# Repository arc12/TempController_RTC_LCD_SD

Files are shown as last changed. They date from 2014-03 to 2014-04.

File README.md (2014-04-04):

Multiple DS18B20 temperature sensors with LCD display, SD card logging, remote control via Serial/USB, real time clock, and up to control an output.

Intended for compilation in Atmel Studio and deployment on a custom ATMega328 based circuit. See source code for notes on use with Arduino IDE.

Various library dependencies not in github yet (will be separate repos). See *.atsln

The idea of this is to have 3 temp sensors: one in a well inside the beer (5 gallon bucket), one inside a ply-wood box (contains a heater pad and the bucket), and one in the outside room. Logging temperature for all three will give an idea of the thermal properties of the assembly and of the heat produced by fermentation. In the first instance, a very simple control rule will be used, taking only the temperature from in the wort and testing for a min temperature with fixed hysteresis. See the MS Word Doc.

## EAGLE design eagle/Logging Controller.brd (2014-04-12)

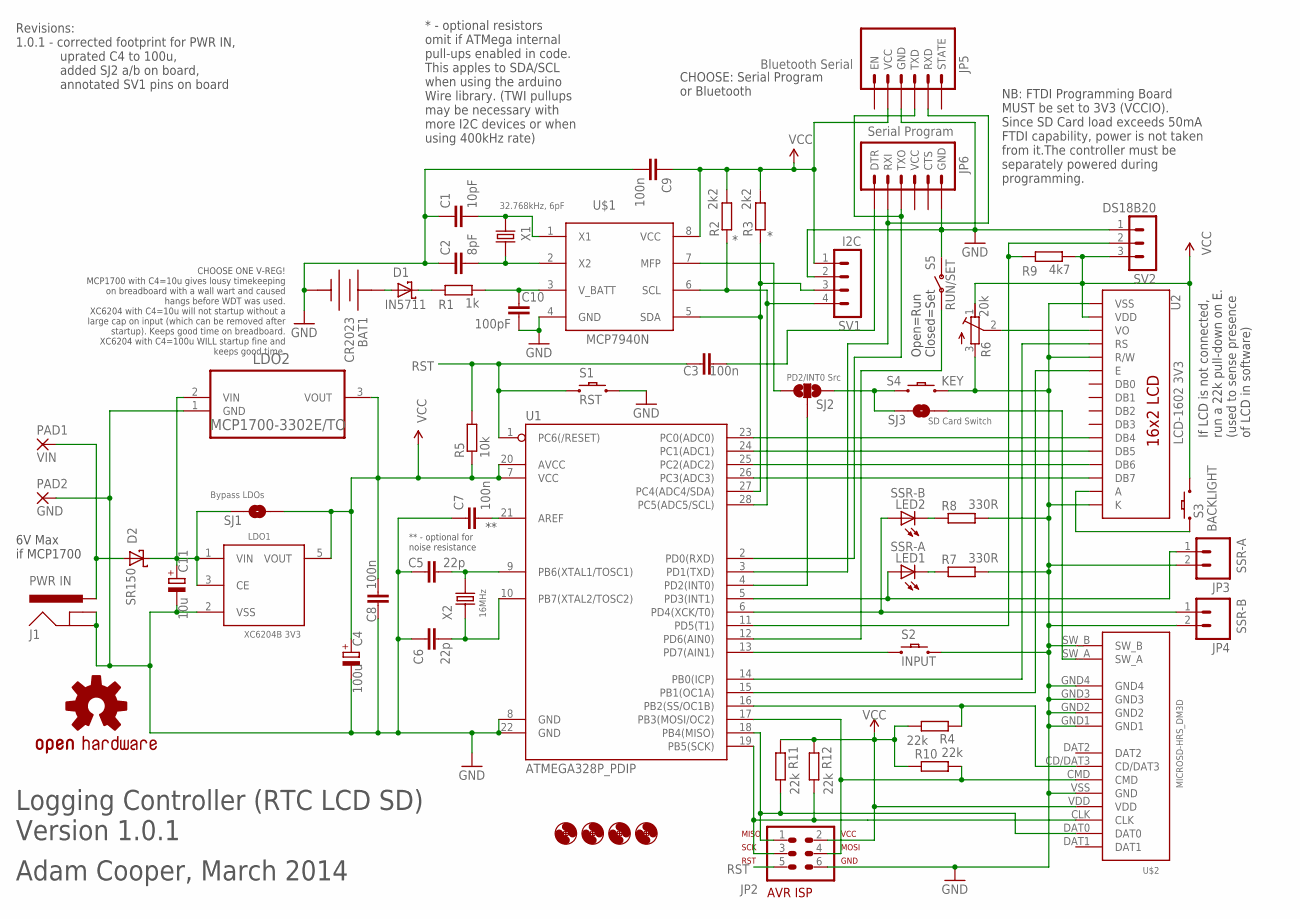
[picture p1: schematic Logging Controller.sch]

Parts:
BAT1: CR2023; KEYSTONE3003
C1: 10pF; C025-024X044
C2: 8pF; C025-024X044
C3, C7, C8, C9: 100n; C025-024X044
C4: 100u; E2,5-5
C5, C6: 22p; C025-024X044
C10: 100pF; C025-024X044
C11: 10u; E2,5-5
D1: IN5711; DO35-7
D2: SR150; DO-41
H1, H2, H3, H4: MOUNT-HOLE3.0_REDUCED; 3,0
J1: PWR IN; POWER_JACK_SLOT2
JP2: AVR-ISP; AVR-ISP-6
JP3: SSR-A; 1X02
JP4: SSR-B; 1X02
JP5: Bluetooth Serial; BT_MOD_ROUND
JP6: Serial Program; 1X06
LDO1: XC6204B 3V3; SOT23-5
LDO2: MCP1700-3302E/TO; TO127P254X495-3
LED1: SSR-A; LED5MM
LED2: SSR-B; LED5MM
LOGO1: OSHW-LOGOS; OSHW-LOGO-S
PAD1: VIN; 2,54/1,1
PAD2: GND; 2,54/1,1
R1: 1k; 0204/7
R2, R3: 2k2; 0204/7
R4, R10, R11, R12: 22k; 0204/7
R5: 10k; 0204/7
R6: 20k; RTRIMT93YB
R7, R8: 330R; 0204/7
R9: 4k7; 0204/7
S1: RST; TACTILE-PTH
S2: INPUT; OFF_BOARD_SPST
S3: BACKLIGHT; OFF_BOARD_SPST
S4: KEY; OFF_BOARD_SPST
S5: RUN/SET; SWITCH-SPST-OFFBOARD
SJ1: Bypass LDOs; SJ_2S-NO
SJ2: PD2/INT0 Src; SJ_3
SJ3: SD Card Switch; SJ_2S-NO
SV1: I2C; MA04-1
SV2: DS18B20; MA03-1
U1: ATMEGA328P_PDIP; DIL28-3@1
U2: LCD-1602 3V3; LCD-16X2_NOSILK
U$1: MCP7940N; DIL08
U$2: MICROSD-HRS_DM3D; DM3D
X1: 32.768kHz, 6pF; TC26H
X2: 16MHz; HC49U-V

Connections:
GND: BAT1.NEG, C1.1, C2.1, C4.-, C5.1, C6.1, C7.1, C8.1, C9.2, C10.1, C11.-, J1.GND, J1.GND2 (GNDBREAK), JP2.6, JP3.2, JP4.2, JP5.4 (GND), JP6.6 (GND), LDO1.2 (VSS), LDO2.1 (GND), PAD2.1, R6.3 (E), R7.2, R8.2, S1.3 (2), S2.P$2 (2), S4.P$2 (2), S5.1 (O), SV1.2, SV2.1, U1.8 (GND), U1.22 (GND), U2.1 (VSS), U2.5 (R/W), U2.16 (K), U$1.4 (GND), U$2.GND1, U$2.GND2, U$2.GND3, U$2.GND4, U$2.SW_B, U$2.VSS (GND)
unnamed: R9.1, SV2.2, U1.11 (PD5(T1))
unnamed: R4.1, U1.16 (PB2(SS/OC1B)), U$2.CD/DAT3
unnamed: U1.14 (PB0(ICP)), U2.4 (RS)
unnamed: U1.15 (PB1(OC1A)), U2.6 (E)
unnamed: U1.23 (PC0(ADC0)), U2.11 (DB4)
unnamed: U1.24 (PC1(ADC1)), U2.12 (DB5)
unnamed: U1.25 (PC2(ADC2)), U2.13 (DB6)
unnamed: U1.26 (PC3(ADC3)), U2.14 (DB7)
unnamed: S3.P$1 (1), U2.15 (A)
unnamed: S2.P$1 (1), U1.13 (PD7(AIN1))
unnamed: S5.2, U1.12 (PD6(AIN0))
unnamed: JP4.1, LED2.A, U1.6 (PD4(XCK/T0))
unnamed: JP3.1, LED1.A, U1.5 (PD3(INT1))
unnamed: LED2.K (C), R8.1
unnamed: LED1.K (C), R7.1
unnamed: S4.P$1 (1), SJ2.3, SJ3.1
unnamed: SJ2.2, U1.4 (PD2(INT0))
unnamed: R6.2 (S), U2.3 (VO)
unnamed: SJ3.2, U$2.SW_A
unnamed: SJ2.1, U$1.7 (MFP)
unnamed: JP5.3 (TXD), JP6.3 (TXO), U1.2 (PD0(RXD))
unnamed: JP2.4, R10.2, U1.17 (PB3(MOSI/OC2)), U$2.CMD
unnamed: JP2.1, R11.2, U1.18 (PB4(MISO)), U$2.DAT0
unnamed: JP5.2 (RXD), JP6.2 (RXI), U1.3 (PD1(TXD))
unnamed: R3.1, SV1.3, U1.27 (PC4(ADC4/SDA)), U$1.5 (SDA)
unnamed: R2.1, SV1.4, U1.28 (PC5(ADC5/SCL)), U$1.6 (SCL)
unnamed: C1.2, U$1.1 (X1), X1.2
unnamed: C2.2, U$1.2 (X2), X1.1
unnamed: BAT1.POS, BAT1.POS1 (POS), D1.A
unnamed: D1.C, R1.1
unnamed: C10.2, R1.2, U$1.3 (V_BATT)
unnamed: C11.+, D2.C, LDO1.1 (VIN), LDO1.3 (CE), LDO2.2 (VIN), SJ1.1
unnamed: D2.A, J1.POS (PWR), PAD1.1
unnamed: C5.2, U1.9 (PB6(XTAL1/TOSC1)), X2.2
unnamed: C3.2, JP6.1 (DTR)
unnamed: C6.2, U1.10 (PB7(XTAL2/TOSC2)), X2.1
unnamed: JP2.3, R12.2, U1.19 (PB5(SCK)), U$2.CLK
unnamed: C7.2, U1.21 (AREF)
RST: C3.1, JP2.5, R5.2, S1.1, U1.1 (PC6(/RESET))
VCC: C4.+, C8.2, C9.1, JP2.2, JP5.5 (VCC), LDO1.5 (VOUT), LDO2.3 (VOUT), R2.2, R3.2, R4.2, R5.1, R6.1 (A), R9.2, R10.1, R11.1, R12.1, S3.P$2 (2), SJ1.2, SV1.1, SV2.3, U1.7 (VCC), U1.20 (AVCC), U2.2 (VDD), U$1.8 (VCC), U$2.VDD

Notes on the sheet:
Adam Cooper, March 2014
Logging Controller (RTC LCD SD) Version 1.0.1
Open=Run Closed=Set
* - optional resistors omit if ATMega internal pull-ups enabled in code. This apples to SDA/SCL when using the arduino Wire library. (TWI pullups may be necessary with more I2C devices or when using 400kHz rate)
6V Max if MCP1700
** - optional for noise resistance
NB: FTDI Programming Board MUST be set to 3V3 (VCCIO). Since SD Card load exceeds 50mA FTDI capability, power is not taken from it.The controller must be separately powered during programming.
CHOOSE ONE V-REG! MCP1700 with C4=10u gives lousy timekeeping on breadboard with a wall wart and caused hangs before WDT was used. XC6204 with C4=10u will not startup without a large cap on input (which can be removed after startup). Keeps good time on breadboard. XC6204 with C4=100u WILL startup f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
If LCD is not connected, run a 22k pull-down on E. (used to sense presence of LCD in software)
CHOOSE: Serial Program or Bluetooth
Revisions: 1.0.1 - corrected footprint for PWR IN, uprated C4 to 100u, added SJ2 a/b on board, annotated SV1 pins on board

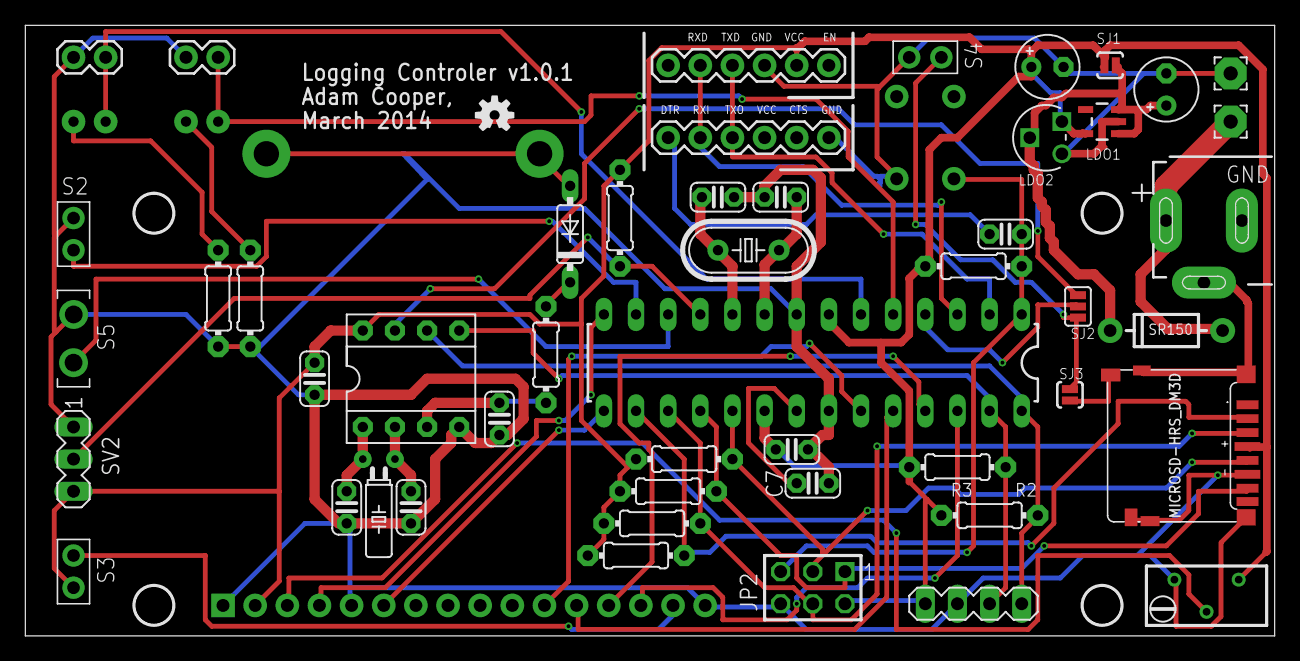
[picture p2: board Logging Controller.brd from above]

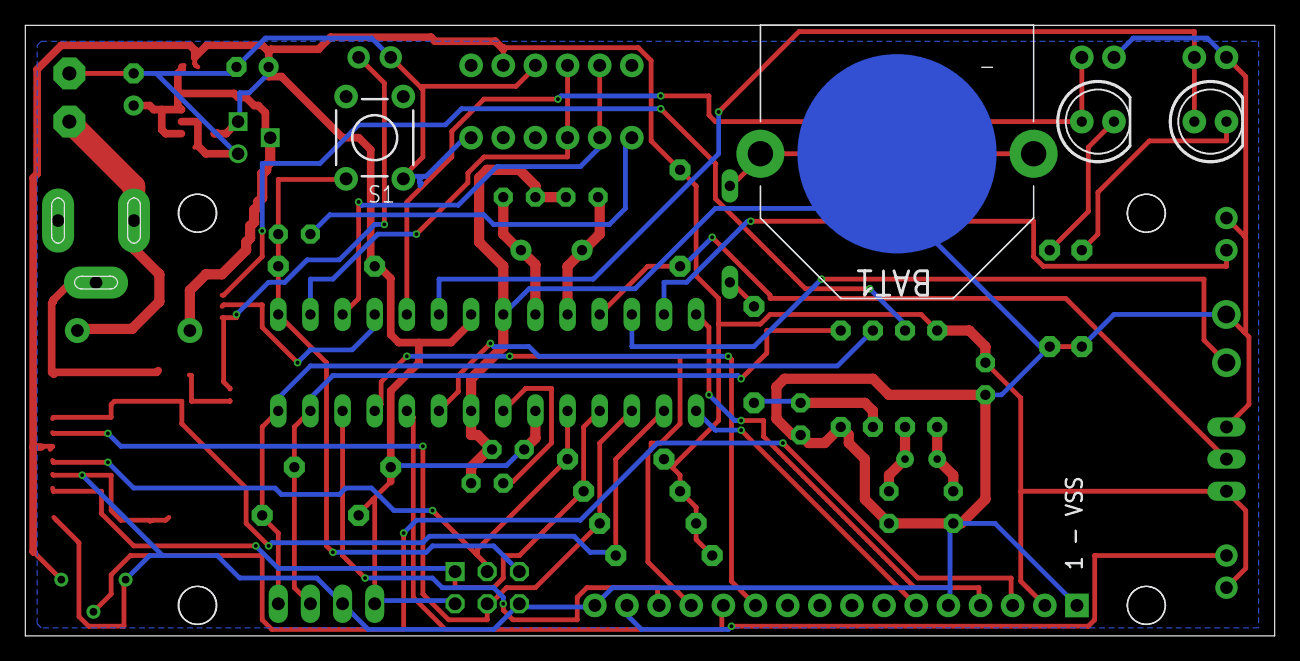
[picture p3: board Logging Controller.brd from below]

Board: 2 copper layers, 98.7 x 48.2 mm, 59 parts (5 on the bottom side), 41 nets.

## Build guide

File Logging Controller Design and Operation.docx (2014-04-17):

# Logging Temp Controller v1

If hardware (schematic and layout) and software have mutually dependent changes, use a new full version number. Use “dot” minor versions for functional changes without HW/SW interdependency. Use “double-dot” sub-minor for bug fix changes. E.g. a PCB layout bug fix to a v1 would number the PCB only as v1.0.1

# Technical Issues

## Power

Assumed to be a 5V wall-wart regulated down to 3V3 because of SD card requirements. Power is NOT taken from USB, even when connected (the internal 3V3 regulator in a FT232R is not rated to deliver sufficient current for SD Card).

Two options for LDOs are accommodated. Only use one!

NB if programming with a FT232RL board, it MUST be set to 3V3 I/O.

## Solder Jumpers

SJ1: bypass LDO if 3V3 supply is used.

SJ2: select input to PD2, either a) use to get a square wave or alarm interrupt from the MCP7940, or b) use to sense a keypress on S4 or SD card insertion

SJ3: connect SD card insertion switch. S4 should be omitted in this case

Normal use expected to have SJ1 open, SJ2 to option (b) and SJ3 closed.

## Omitted Components

S4 – because of SD card switch

R2, R3 - when using the Arduino Wire library, ATMega internal pull-ups enabled in code. TWI pullups may be necessary with more I2C devices or when using 400kHz rate)

JP4 – not expecting to control 2 outputs, “for future use” (LED2 used as over-range signal)

SV1 – for possible extra I2C components “future use”

JP2 – don’t expect to use ISP

C7 – there is no ADC use. This is present “for future use”.

** it may be possible to omit some/all of the 22k pull-ups on the SD Card lines but these seem to be generally recommended.

## LCD Notes

This is a 3V3 device. Some 3V3 versions have peculiar requirements for V0.

The LCD may be omitted. Place a 22k resistor from E to ground; the software will sense this and skip LCD output code.

## Watchdog

Unless #define WATCHDOG has been commented out, the watchdog timer is set to 8s and a delay of >8s between calling loop() will cause a reset. This is useful because if there is a crash while outA is switched on, the brew will overheat (or if off, over-cool!).

# User Notes

## Logging to SD Card and to Serial

SD card presence is detected on startup. Logging to the card will be skipped if no card is detected and the log data emitted to Serial.

Assuming the SD card receptacle has an insertion switch and providing the solder jumpers SJ2 and SJ3 are set correctly

- If the SD card is removed while the system is on, then the Serial will be used.
- Card insertion after startup will enable logging to the card.

Removing the card during a log write may cause problems but otherwise, it should be OK to remove and insert a card while the controller is operating. To be safe, do not remove in run mode. Newly acquired data is lost when no card is inserted (no buffering).

## Logging to CSV

The log data is largely self-explanatory, except that the columns after time, and before temperature are: outA, outB and the status byte. The status byte (currently) reads 0 except for the first log after a reset, when it indicates the cause of the reset (power-on, manual, watchdog). See below for outA and outB.

## Temperature

### Sensors

Maxim DS18B20 temperature sensors have 64 bit IDs but these are used internally and matched to a zero-based index in a lookup table is stored in EEPROM, where the 1st stored ID is "sensor 0" etc. On first startup, discovered sensors have their IDs stored to EEPROM in the order they are found by OneWire library. In future the same sensor will have the same index so to know up-front which probe will be 0, 1, 2 etc, you should connect one probe at a time with a reset/restart to cause it to be detected. Otherwise use the *SWAP and *SCAN commands. A look-up array is kept to record which sensors are actually attached (some may be disconnected but retain a record in the EEPROM).

### Control Rules

This is simple min/max system. The values of Tmin and Hysteresis are set via serial commands.

If T>=Tmin+Hysteresis, then output A is turned off. If T<Tmin then the output is turned on. In between Tmin and Tmin+Hysteresis, the output remains in the same state. The value is logged; a 1 means the heater is turned on.

Only ONE of the temperature probes is used to control the output. It will be the connected sensor at index 0 in the EEPROM table if that sensor is connected. Otherwise, it will be the first sensor detected (1-wire detection order).

Output B is not used for control but, in the current version, is used to light a LED to show that T>Tmin+Hysteresis. It will turn off again once the temperature drops to T<=Tmin+Hysteresis. i.e. output B signals a “too high” or over-shoot condition. The value is logged; a value of 1 means the temperature is above range.

Outputs only change in run mode (see below).

## Start-up Reset

The output B LED will light for 0.5s on startup.

Following startup a non-zero status value will be written to the first logged record. Depending on the optiboot version[^1], the status byte indicates the cause by a status byte in which the high nibble is F and the low nibble is given by the MCUSR register:

- Bit 3 – WDRF: This bit is set if a Watchdog System Reset occurs
- Bit 2 – BORF: This bit is set if a Brown-out Reset occurs.
- Bit 1 – EXTRF: This bit is set if an External Reset occurs.
- Bit 0 – PORF: This bit is set if a Power-on Reset occurs.

~~If the pushbutton (S2) is held closed during power-on or manual reset then any previously-stored temperature sensor IDs (in EEPROM) are cleared before scanning for new attached sensors.~~

## Modes

S5 selects “set” or “run” mode.

In set mode:

- serial commands may be sent (see below) and the push button (S2) may be used to cycle the set-minimum temperature in 0.5C increments from 0 to 30C.
- Changes made in set mode are applied immediately to the real time clock but other settings are saved to EEPROM only on return to run mode.
- The outB LED is illuminated as a warning (out A is not controlled, and logging is suspended in set mode)

In run mode:

- Serial commands are ignored
- The push button (S2) may be pressed to cause the display to cycle through the temperature readings according to all attached probes. During this time, output control is suspended. Holding the button for more than 8s will cause a reset (which is harmless).

## Serial Commands – Setup and Testing

Send * followed by a four letter command, optionally followed by an argument (no spaces). Send CR after the command. (LF will be ignored but it causes a short delay, so it is best not sent).

ECHO echo test – follow the command with a string

GETD get date string

SETD set date using YYYY-MM-DD string

GETT get time string

SETT set time using HH:MM:SS string

LOGN change name of log file. Must be no longer than 8.3 and must be at least 1.3

LOGI change logging interval in seconds. this is determined by arduino function millis() not the RTC. An integer

TEMP read all attached temp sensors and emit logging string.

TMIN change low temperature threshold for controller. output turns on if T less than this value. May be a float. Maybe negative

THYS change temperature hysteresis. output turns off if T >= TMIN+THYS. May be a float

OUTI change interval in seconds between controller deciding whether to switch on or off (according to TMIN and THYS). An integer

OUTS read the output status over serial

RELD clear stored values in EEPROM. This stops the device and must be followed by a hard reset.

SWAP swap temp sensor IDs in EEPROM and re-scan. Argument is the single digit sensor index (1,2...) to swap with the sensor ID at index=0.

SCAN clears IDs stored in EEPROM and does a rescan of attached sensors and reports the IDs via Serial. NB if more than one sensor then it may be necessary to use *SWAP so that the desired sensor is used for control

E.g. send “*ECHO” or “*GETT” or “*SETT12:43:21”

[^1] The high nibble will always be set after startup. If the optiboot version is late enough, the low nibble will be correct, otherwise it is probably indeterminate (but has been observer to be 0xF)

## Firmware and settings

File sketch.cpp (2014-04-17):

/* ===================================================================
* ****              TempController RTC LCD SD                    ****
*
* Multiple DS18B20 temperature sensors with LCD display, SD card
* logging, remote control via Serial/USB, real time clock, and up to
* control an output (2 outputs in principle but only 1 used).
* ===================================================================
*
* Copyright 2014 Adam Cooper
*
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
* You should have received a copy of the GNU General Public License
* along with this software.  If not, see <http://www.gnu.org/licenses/>.
*/

// !!!!!!!!!!! this version uses SdFat library from http://code.google.com/p/beta-lib/downloads/list
// specifically SdFatBeta20130207.zip in an effort to reduce SRAM use, which causes crashing due to overflow
// with the normal Arduino SD library

#include <Arduino.h>
//the following libraries include .h from the .cpp so include .cpp!
#include <MCP7940N.cpp>
#include <I2CUtils.cpp>
#include <EEPROMUtils.cpp>
#include <Wire.cpp>
#include <EEPROM.cpp>
//#include <SD.cpp>
#include <LiquidCrystal.cpp>
#include <OneWire.cpp>
#include <SdFat.cpp> //new lib


//deeper includes, dependencies for SD and Wire
#include <twi.c>
//#include <Sd2Card.cpp>
//#include <SdFile.cpp>
//#include <SdFat.h>
//#include <SdFatUtil.h>
//#include <SdVolume.cpp>
//#include <File.cpp>
#include <SdFile.cpp>
#include <SdBaseFile.cpp>
#include <SdVolume.cpp>
#include <Sd2Card.cpp>

// Function prototypes go here (telling the compiler these functions exist).
void setup();
void loop();

void reportId(uint8_t sensorId[8]);
void saveParamsToEEPROM();
void loadParamsFromEEPROM();
void detectAttachedSensors();
void readSensors();
void stringT(float T, char str2[6]);
void logData();
void controlOutputs();
void readRTC();
void doSerialCommands();
int encodeCommand(char cmd[5]);
void buildLogString();
void sdISR();
void spiFloat();

/* Below this point, should be what you need for an Arduino IDE sketch (+ the necessary library includes) */

//these lines are to capture MCUSR as intercepted by optiboot before it resets it.
uint8_t resetFlags __attribute__ ((section(".noinit")));
void resetFlagsInit(void) __attribute__ ((naked)) __attribute__ ((section (".init0")));
void resetFlagsInit(void)
{
	// save the reset flags passed from the bootloader
	__asm__ __volatile__ ("mov %0, r2\n" : "=r" (resetFlags) :);
}

//#define DEBUG //comment out to suppress trace output to Serial
#define WATCHDOG //comment out to suppress use of the watchdog timer, which will cause a reset in the event of a hang (which seems to be associated with powering from a wall wart)

/* Pin definition */
// I2C is (hardware) fixed as A4=SDA, A5=SCL
// SD Card uses SPI and the default SS so uses pins 10-13 (determined by hardware)
// LCD
const int lcdRS = 8;
const int lcdE = 9;
const int lcdD4 =A0;
const int lcdD5 = A1;
const int lcdD6 = A2;
const int lcdD7 = A3;
// pin 2 is for the hardware SD card switch, which triggers an interrupt. May also be configured via solder jumpers for
// - an extra push button input or an interrupt driven from MFP pin
const int sdSwitch = 2;
// user controls
const int modeSwitchPin = 6;//high for run mode, low for setting-mode (USB and button control)
const int pushSwitchPin = 7;//user pulsable button
//outputs for relay control
const int outAPin = 3;
const int outBPin = 4; //output B is not currently used
// 1-wire temp sensors
const int sensorPin = 5;   //a 4.7k pull-up resistor is necessary

#define RUN_MODE HIGH// for reading modeSwitch

#define MAX_1WIRE_SENSORS 3 //max number of 1-wire sensors. Large values may exceed available memory!!!
#define MAX_FIELD_LENGTH 26+6*MAX_1WIRE_SENSORS //max length of a record in logged data, YYYY-MM-DD,HH:MM:SS,A,B,status{,TTT.T}*MAX_1WIRE_SENSORS

/* used to decode commands into an integer */
#define CMD_ECHO 0 //echo test
#define CMD_GETD 1 //get date string
#define CMD_SETD 2 //set date using YYYY-MM-DD string
#define CMD_GETT 3 //get time string
#define CMD_SETT 4 //set time using HH:MM:SS string
#define CMD_LOGN 5 //change name of log file. Must be no longer than 8.3 and must be at least 1.3 (e.g. a.csv)
#define CMD_LOGI 6 //change logging interval in seconds. this is determined by arduino function millis() not the RTC. An integer
#define CMD_TEMP 7//read all attached temp sensors and emit logging string.
#define CMD_TMIN 8//change low temperature threshold for controller. output turns on if T less than this value. May be a float. Maybe negative
#define CMD_THYS 9//change temperature hysteresis. output turns off if T >= TMIN+THYS. May be a float
#define CMD_OUTI 10 //change interval in seconds between controller deciding whether to switch on or off (according to TMIN and THYS). An integer
#define CMD_OUTS 11 //read the output status over serial
#define CMD_RELD 12 //clear stored values in EEPROM. This stops the device and must be followed by a hard reset.
#define CMD_SWAP 13 //swap temp sensor IDs in EEPROM and re-scan. Argument is the single digit sensor index (1,2...) to swap with the sensor ID at index=0.
#define CMD_SCAN 14 //does a rescan of attached sensors and reports the IDs via Serial


//the number of characters expected in the parameter following a command.
//if there are fewer characters available, an error will be signalled and the command ignored
#define MAX_PARAM_LENGTH 12 //the max paramLength
uint8_t paramLength[15];

#define EEPROM_1WIRE_BASE 0x120//address of storage for up to MAX_1WIRE_SENSORS sets of 8 byte (64bit) device IDs, incl CRC
#define EEPROM_PARAMS_SIZE 0x20 //allow 32 bytes for stored params (not all used)
#define EEPROM_PARAMS_BASE 0x100 // 24 bytes for logFileName[12], Tmin, Thys, logInterval, controlInterval

// global variables
//lcdPresent may become true in setup(). Defaults to false => the LCD is not connected
//If LCD not used then a pull-down on LCD E should be inserted instead (if it is desired for the software to skip LCD code chunks)
bool lcdPresent = false;
LiquidCrystal lcd(lcdRS, lcdE, lcdD4, lcdD5, lcdD6, lcdD7);// initialize the LCD library
OneWire  oneWire(sensorPin);
MCP7940N rtc;//The real time clock
SdFat sd;//new lib
SdFile myFile;//new lib
boolean hasSD = false; //is there an SD card
volatile boolean sdInit = false; //whether an SD card initialise is needed on loop. May happen if hot insertion.
boolean sensorsFound=false;
float T[MAX_1WIRE_SENSORS];//for temperature readings
uint8_t controlSensorIndex = 0xFF;//stores the index into T[] to be used as the control temperature. Will be the first detected sensor that is connected at start-up
uint8_t numStoredSensorIds=0;//how many sensor ids stored in EEPROM
uint8_t connectedSensorIds[MAX_1WIRE_SENSORS][8];//holds the sensors actually found against their index number (or a not-found placeholder)

char logString[MAX_FIELD_LENGTH+1]="";
char time[9]=""; //note fixed length format HH:MM:SS + null termination (needed for sprintf)
char date[11]="";//note fixed length format YYYY-MM-DD
boolean runMode = true;
boolean lastRunMode = true;
long lastLogAt = 0;//store value of millis() when last record was logged
long lastControlAt = 0;//store value of millis() when control conditions were last checked
//outputs are turned off initially
boolean outA=false;
boolean outB= false;
//flags logged to last column
//typically the value of bits 3-0 of the MCU status register after startup, when bits 7-4 are set to 1111
uint8_t status =0;

// default values, may be changed according to EEPROM or commands via USB
char logFileName[13] = "log.csv";//as LOGN
unsigned long logInterval=10;// as LOGI
float Tmin = 18.0;// as TMIN
float Thys = 1.0;//as THYS
unsigned long controlInterval = 30;//as OUTI

void setup(){
	//set the status on a reset. Unfortunatly, optiboot boot loader resets MCUSR so this will always set 
	// status to 0xF0, whatever the reset cause but the older arduino bootloader preserves it.
	// A later version of optiboot is believed to pass the value of MCUSR in a register. This is coded for but
	// has not been tested (optiboot version not high enough).
	// Alternatively, just program over the bootloader!
	status=0xF0 | resetFlags;
	
	//enable the watchdog timer with an 8s timeout
	#ifdef WATCHDOG
	cli();//disable interrupts
	__asm__ __volatile__ ("wdr");//reset watchdog timer
	/* Start timed equence */
	WDTCSR |= (1<<WDCE) | (1<<WDE);
	/* Set new prescaler(time-out) value = 1024K cycles (~8 s) */
	WDTCSR = (1<<WDE) | (1<<WDP3) | (1<<WDP0);
	sei();// enable_interrupt
	#endif
	
	//the min param lengths
	paramLength[CMD_ECHO]=0;
	paramLength[CMD_GETD]=0;
	paramLength[CMD_SETD]=10;
	paramLength[CMD_GETT]=0;
	paramLength[CMD_SETT]=8;
	paramLength[CMD_LOGN]=4;
	paramLength[CMD_LOGI]=1;
	paramLength[CMD_TEMP]=0;
	paramLength[CMD_TMIN]=1;
	paramLength[CMD_THYS]=1;
	paramLength[CMD_OUTI]=1;
	paramLength[CMD_OUTS]=0;
	paramLength[CMD_RELD]=0;
	paramLength[CMD_SWAP]=1;
	paramLength[CMD_SCAN]=0;

	// set the conventional IO pins. NB pull-ups
	pinMode(modeSwitchPin,INPUT_PULLUP);
	pinMode(pushSwitchPin,INPUT_PULLUP);
	pinMode(outAPin, OUTPUT);
	pinMode(outBPin, OUTPUT);
	pinMode(10, OUTPUT); //SPI Slave-Select
	
	// set up the SD card switch as an interrupt. Pin2 is interrupt 0. Only trigger on edge
	pinMode(sdSwitch,INPUT_PULLUP);
	attachInterrupt(0, sdISR, CHANGE);//was FALLING
	
	//is LCD connected. If LCD not used then a pull-down on LCD E should be inserted instead (if it is desired for the software to skip LCD code chunks)
	pinMode(lcdE, INPUT_PULLUP);
	lcdPresent = digitalRead(lcdE);

	// initialise libraries
	Serial.begin(9600); //Will be outputting to serial
	Wire.begin();//join bus as a master NB this is needed since MCP7940N uses I2C
	rtc.initialise();//initialise the RTC with defaults
	if( lcdPresent){
		pinMode(lcdE, OUTPUT);
		// set up the LCD's number of columns and rows:
		lcd.begin(16, 2);
		// Print a message to the LCD.
		lcd.print("Starting!");
	}
	
	//indicate startup to the user via the OUTB LED
	digitalWrite(outBPin, HIGH);
	delay(500);
	digitalWrite(outBPin, LOW);
	
	// try to initialise SD card.
	// alt use sd.begin(chipSelect, SPI_HALF_SPEED)
	hasSD=sd.begin();//was SD.begin(10)
	if(!hasSD){
		Serial.println("No SD card");
		spiFloat();
		//alt sd.initErrorPrint()
	}
	
	//if pushbutton is held (active low) on startup then clear stored temp sensor IDs prior to detecting attached sensors
	//if(!digitalRead(pushSwitchPin)){
		//EEPROMUtils::clearBlock(EEPROM_1WIRE_BASE, MAX_1WIRE_SENSORS*8);
		//while(digitalRead(pushSwitchPin));//wait for release since the button is used in set mode inside loop()
	//}

	detectAttachedSensors();

	// check RTC found
	#ifdef DEBUG
	rtc.dumpRegisters();
	#endif

	// setup MFP to trigger interrupt
	rtc.mfpOsc(MCP7940N_RS_1);//set MFP to output 1Hz

	// check EEPROM for operating parameters.
	//If the first byte is 0xFF there are none saved, so save the defaults above. Otherwise load values
	if(EEPROM.read(EEPROM_PARAMS_BASE)==0xFF){
		saveParamsToEEPROM();
	}
	else{
		loadParamsFromEEPROM();
	}
	#ifdef DEBUG
	//commented out because RAM is tight
	//Serial.print("logInterval=");
	Serial.println(logInterval);
	//Serial.print("controlInterval=");
	Serial.println(controlInterval);
	//Serial.print("Tmin=");
	Serial.println(Tmin);
	//Serial.print("Thys=");
	Serial.println(Thys);
	//Serial.print("logFileName=");
	Serial.println(logFileName);
	#endif

	if(  lcdPresent){
		lcd.clear();
	}
}

/* NOTES:
1. changing settings using Serial/USB or manual button-pressing (for Tmin) will not save the values to EEPROM
until re-entering run mode. */
void loop(){
	
	#ifdef WATCHDOG
	 __asm__ __volatile__ ("wdr");//reset watchdog timer
	#endif
	
	//is an SD card re-initialise required? This will be the case if an interrupt was triggered by a SD card hot insertion
	if(sdInit){
		hasSD=sd.begin();
		if(!hasSD){
			lcd.clear();
			lcd.print("SD Card Error");
			delay(1000);
			lcd.clear();
			spiFloat();
		}
		sdInit=false;
	}
	
	//first check whether run mode or set mode.
	runMode = (digitalRead(modeSwitchPin) == RUN_MODE);
	
	//single-shot special treatment when the run mode changes
	if(runMode!=lastRunMode){
		//save any changed parameters to EEPROM when leaving set mode
		if(runMode){
			saveParamsToEEPROM();
			//turn off outB (setup mode warning)
			digitalWrite(outBPin, LOW);
		}else{			
			//turn off outB (setup mode warning)
			digitalWrite(outBPin, HIGH);
		}
		
		//Show change of run mode on LCD
		if(  lcdPresent){
			lcd.clear();
			lcd.print(runMode?"Run Mode":"Set Mode");
			delay(1000);
			lcd.clear();
		}
		
		lastRunMode = runMode;
	}

	if(runMode){
		if(sensorsFound){
			//check whether the control or logging interval has been met.
			unsigned long t= millis();
			boolean needControl=(t-lastControlAt >= controlInterval*1000);
			boolean needLog=(t-lastLogAt >= logInterval*1000);
			//only read temp once for either control  or logging but always read if LCD present
			if(needControl || needLog ||  lcdPresent){
				//read real time clock first.
				readRTC();
				readSensors();
			}
			//check whether the output should change, including over-shoot alert
			if(needControl){
				lastControlAt = millis();
				controlOutputs();
			}
			//logging
			if(needLog){
				lastLogAt = millis();
				logData();
			}
			//check if button held to request all sensor temperature values are cycled
			while(!digitalRead(pushSwitchPin)){
				if(lcdPresent){
					lcd.clear();
					char sT[6];
					//loop over all stored sensors and check which were found
					for(uint8_t i=0;i<numStoredSensorIds;i++){
						if(connectedSensorIds[i][0] != 0xFF){
							//if sensor connected then emit the ID on the first row of the LCD
							// followed by the temp on the second row
							lcd.setCursor(0, 0);//row=0 col=0
							for(uint8_t j=0; j<8; j++){
								lcd.print(connectedSensorIds[i][j], HEX);
							}							
							lcd.setCursor(0, 1);//row=1 col=0
							lcd.print("Temp=");
							stringT(T[i],sT);
							lcd.print(sT);
							delay(1000);
						}
					}		
					lcd.clear();
				}				
			}
			//update LCD for run mode
			if(  lcdPresent){
				char strTc[6];
				stringT(T[controlSensorIndex], strTc);
				lcd.setCursor(0, 0);//row=0 col=0
				lcd.print("Temp=");
				lcd.print(strTc);
				lcd.print(outA?" ON ":" OFF");
				lcd.setCursor(0, 1);//row=1 col=0
				lcd.print("Status: waiting");
				lcd.setCursor(8, 1);				
				if(needControl){
					lcd.print("ctrl   ");
				}else if(needLog && hasSD){
					lcd.print("log    ");
				}
			}
			}else{
			if(  lcdPresent){
				//report no sensors to LCD
				lcd.setCursor(0, 0);//row=0 col=0
				lcd.print("No sensors!");
			}
			
		}//end if(runmode)
	}
	else{
		//check for commands from Serial and execute them accordingly
		doSerialCommands();
		
		//check for button held to change threshold
		if(!digitalRead(pushSwitchPin)){
			Tmin = 0.5+Tmin;
			if(Tmin>30.0){
				Tmin=0.0;
			}
		}
		
		//update LCD for set mode
		if(  lcdPresent){
			readRTC();//keep the time up-dated during setup mode
			char strTmin[6], strThys[5];
			stringT(Tmin, strTmin);
			int iT = (int)Thys;
			int dT = (int)(10*(Thys-(float)Thys));
			sprintf(strThys,"%2d.%1d",iT,dT);
			lcd.setCursor(0, 0);//row=0 col=0
			lcd.print("Min=");
			lcd.print(strTmin);
			lcd.print(" H=");
			lcd.print(strThys);
			lcd.setCursor(0, 1);//row=1 col=0
			lcd.print(date);
			lcd.print(' ');
			lcd.print(time);
		}
	}

	delay(300);
}
/* ===================================
*       Misc Functions
* ====================================*/
//ISR - set a flag for use in loop() to show SD card insertion/removal, also disable SD writing.
// Writing will be promptly re-enabled only if this was an insertion
void sdISR(){
	sdInit = (digitalRead(sdSwitch)==LOW);
	hasSD = false;
	spiFloat();
}

//make sure the SPI bus is in a sensible floating state.
//this is used if a sd.begin() fails or card removal is detected.
void spiFloat(){
	digitalWrite(10, HIGH); // Slave select is active low
	pinMode(11, INPUT); //MOSI
	pinMode(12, INPUT); //MISO (should already be input)
	pinMode(13, INPUT); //SCK
}

/* ====================================
*           EEPROM Functions
* ====================================*/
void saveParamsToEEPROM(){
	word addr=EEPROM_PARAMS_BASE;
	EEPROMUtils::saveLong(&addr, logInterval);
	EEPROMUtils::saveLong(&addr, controlInterval);
	EEPROMUtils::saveFloat(&addr, Tmin);
	EEPROMUtils::saveFloat(&addr, Thys);
	uint8_t lf[13];
	memcpy(lf,logFileName,13);
	EEPROMUtils::saveBytes(&addr, lf,13);
}

void loadParamsFromEEPROM(){
	word addr=EEPROM_PARAMS_BASE;
	logInterval = EEPROMUtils::loadLong(&addr);
	controlInterval = EEPROMUtils::loadLong(&addr);
	Tmin = EEPROMUtils::loadFloat(&addr);
	Thys = EEPROMUtils::loadFloat(&addr);
	uint8_t lf[13];
	EEPROMUtils::loadBytes(&addr, lf,13);
	memcpy(logFileName,lf,13);
}

/* ====================================
*    Temperature Sensor Functions
* ====================================*/
void reportId(uint8_t sensorId[8]){
	for(uint8_t i = 0; i < 8; i++) {
		Serial.write(' ');
		Serial.print(sensorId[i], HEX);
	}
}

void detectAttachedSensors(){
	uint8_t sensorId[8];
	// temperature sensors have 64 bit IDs but these are used internally and matched to a zero-based index.
	// a lookup table is stored in EEPROM from EEPROM_1WIRE_BASE address, where the 1st stored ID is "sensor 0" etc
	// on first startup, discovered sensors have their IDs stored to EEPROM in the order they are found by OneWire.
	// in future the same sensor will have the same zero-based index
	// so to know up-front which probe will be 0, 1, 2 etc you should connect one probe at a time with a reset/restart
	// to cause it to be detected
	// a look-up array is kept to record which sensors are actually attached (some may be disconnected but retain a record in the EEPROM)

	controlSensorIndex = 0xFF;
	numStoredSensorIds=0;//this does need setting because CMDs SCAN and SWAP call this fn
	
	// see if EEPROM contains sensor IDs. These will be detected from a valid CRC in the 8th stored byte
	uint8_t storedSensorIds[MAX_1WIRE_SENSORS][8];
	word eepromAddress = EEPROM_1WIRE_BASE;
	Serial.println("IDs in EEPROM:");
	while (numStoredSensorIds<MAX_1WIRE_SENSORS){
		EEPROMUtils::loadBytes(&eepromAddress,sensorId,8);
		if(OneWire::crc8(sensorId, 7) != sensorId[7]){
			eepromAddress -=8;//rewind so that newly discovered sensor ids are stored at the right posn
			break;
		}
		reportId(sensorId);
		Serial.println();
		for(uint8_t j = 0; j<8; j++){
			storedSensorIds[numStoredSensorIds][j] = sensorId[j];
		}
		numStoredSensorIds++;
	}
	
	//look for connected temperature sensors.
	//check if their ID is already stored in EEPROM.
	//If not, append the ID to EEPROM list
	//Either way we then know which index it is so save the ID against that index in connectedSensorIds
	for(uint8_t i=0;i<MAX_1WIRE_SENSORS;i++){
		connectedSensorIds[i][0] = 0xFF;//signifies no sensor with index i was found
		T[i]=0.0;//default temp is 0.0 for any sensor that is not present. This should never be used but may appear as a place-holder in output data
	}
	
	Serial.println();
	Serial.println("Detected: ");
	oneWire.reset_search();
	while (oneWire.search(sensorId)) {
		//report what found
		reportId(sensorId);

		//CRC must be good (if bad a bus error)
		if (OneWire::crc8(sensorId, 7) == sensorId[7]) {
			boolean found=false;
			//check EEPROM list
			for(int i=0; i<numStoredSensorIds;i++){
				if(memcmp(storedSensorIds[i],sensorId,8)==0){ //memcmp returns 0 if they match
					//already known
					for(uint8_t j = 0; j<8; j++){
						connectedSensorIds[i][j] = sensorId[j];
					}
					sensorsFound=true;
					Serial.print(" i=");
					Serial.println(i);
					//the first detected sensor will be used for the control temp unless the sensor at index 0 in the EEPROM is present (when it is used)
					if(controlSensorIndex==0xFF) controlSensorIndex = i;
					if(i==0) controlSensorIndex = 0;

					found= true;
					break;
				}
			}
			if(!found && numStoredSensorIds<MAX_1WIRE_SENSORS){
				//not known so add to EEPROM stored sensor list
				//unless wrong type
				if(sensorId[0]==0x28){
					Serial.print(" i=");
					Serial.print(numStoredSensorIds);
					Serial.println(" *new");

					EEPROMUtils::saveBytes(&eepromAddress, sensorId, 8);
					for(uint8_t j = 0; j<8; j++){
						storedSensorIds[numStoredSensorIds][j] = sensorId[j];
						connectedSensorIds[numStoredSensorIds][j] = sensorId[j];
					}
					sensorsFound=true;
					if(controlSensorIndex==0xFF){
						controlSensorIndex = numStoredSensorIds;
					}
					numStoredSensorIds++;
					}else{
					#ifdef DEBUG
					Serial.println("Not DS18B20!");
					#endif
				}
			}
			}else{
			#ifdef DEBUG
			Serial.println("CRC bad!");
			#endif
		}
	}

	//set precision to 11 bit (0.125Celcius) => 375ms max conversion time
	if(sensorsFound){
		//check each index position, 0xFF denotes no sensor found
		for(uint8_t i=0;i<numStoredSensorIds;i++){
			if(connectedSensorIds[i][0] != 0xFF){
				for(uint8_t j=0; j<8; j++){
					sensorId[j] = connectedSensorIds[i][j];
				}
				oneWire.reset();
				oneWire.select(sensorId);
				oneWire.write(0x4E);//write to scratchpad (3 bytes always)
				oneWire.write(0x00);//TH not used
				oneWire.write(0x00);//TL not used
				oneWire.write(0x5F);//config byte
			}
		}
		}else{
		Serial.println("No sensors");
	}
}
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

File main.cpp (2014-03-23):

/*
 * Copyright 2014 Adam Cooper, based heavily on the work of Elco Jacobs.
 * See http://www.elcojacobs.com/easy-to-use-atmel-studio-project-for-arduino-and-programming-the-arduino-from-python/
 *
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
 * You should have received a copy of the GNU General Public License
 * along with this software.  If not, see <http://www.gnu.org/licenses/>.
 */

/* This is the main routine and library loader to allow arduino sketches and the arduino core libraries to be easily used from
 * within Atmel Studio 6. This version is for "standard" arduinos such as the Uno.
 * In general use, leave main.cpp unchanged except for including necessary core libraries and use sketch.cpp for your arduino sketch
 *
 * You also need to modify Atmel Studio 6 project properties to point it to the right directories for the arduino libraries.
 * To compile this project on your computer, take the following steps:
 * 1. Go the the project properties and change the following options:
 *		In AVR/GNU C++ Compiler --> Directories.
 *			Change the two directories to point to your local Arduino installation. For the second directory, choose the Arduino variant that you are using.
 *			Also add any Arduino libraries that you are using. My directories are:
 *			D:\arduino-1.0.1\hardware\arduino\cores\arduino
 *			D:\arduino-1.0.1\hardware\arduino\variants\standard (for Uno) or ..\leonardo
 *			D:\arduino-1.0.1\libraries\{library-name} <<< add 0 or more, substituting {library-name} accordingly
 *		If you are using an 8 MHz Arduino, also change F_CPU in AVR/GNU C++ Compiler --> Symbols
 * 
 * That is all that is needed! No hassle with makefiles and compiling libraries. You can find all the files that are automatically included under 'Dependencies'.
 *
 *Once all of this has been done, you can File>Export Template to create a project template in which all of these settings are preserved.
 */

#define ARDUINO_MAIN

// Disable some warnings for the Arduino files
#pragma GCC diagnostic push
#pragma GCC diagnostic ignored "-Wsign-compare"
#pragma GCC diagnostic ignored "-Wattributes"
#pragma GCC diagnostic ignored "-Wunused-variable"
#pragma GCC diagnostic ignored "-Wuninitialized"

#include <Arduino.h>
extern "C"{
	#include <pins_arduino.h>
}


/*
* Libraries
*/

// Standard Arduino source files for serial:
#include <HardwareSerial.cpp>

// Other source files, depends on your program which you need
#include <Print.cpp>
#include <New.cpp>
#include <wiring.c>
#include <wiring_digital.c>
#include <wiring_analog.c> //analog read/write functions
#include <WString.cpp>
#include <WMath.cpp>
#include <Stream.cpp>
#include <WInterrupts.c>

// Unused source files:
//#include <wiring_pulse.c>
//#include <wiring_shift.c>
//#include <IPAddress.cpp>

//#include <Tone.cpp>

// Restore original warnings configuration
#pragma GCC diagnostic pop

int main(void)
{
	init();

	setup();
	
	for (;;) {
		loop();
		if (serialEventRun) serialEventRun();
	}
	return 0;
}

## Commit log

2014-03-23 board layout to be refined
    [Logging Controller.brd, Logging Controller.sch]
2014-03-23 tidied silk, adjusted some positions. Thick traces and ground fill
    [Logging Controller.brd, Logging Controller.sch]
2014-03-23 Gerbers as per Seeed CAM file plus board outline and inclusion of values in silk
    [Logging Controller.GBL, Logging Controller.GBO, Logging Controller.GBP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]
2014-04-04 add: 1) use output B to signal over-shoot; 2) in run mode, pressing the button now causes display of all temp sensor values
2014-04-12 v1.0.1 revision, esp fix power in pinout.
    [Logging Controller.brd, Logging Controller.sch]
2014-04-12 add warning LED in setup mode. Better SD card insert/remove behaviour. Some cosmetic display changes.
2014-04-17 changed behaviour of *TEMP command. Made time be updated in setup mode. set SPI to floating condition on SD fail or remove.
    [sketch.cpp]

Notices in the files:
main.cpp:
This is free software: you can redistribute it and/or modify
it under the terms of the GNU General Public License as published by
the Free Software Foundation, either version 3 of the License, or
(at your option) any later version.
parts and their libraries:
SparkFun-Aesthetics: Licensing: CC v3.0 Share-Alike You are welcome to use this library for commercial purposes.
